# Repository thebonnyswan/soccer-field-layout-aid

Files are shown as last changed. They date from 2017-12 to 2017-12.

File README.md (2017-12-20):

# soccer-field-layout-aid
Soccer Field Layout Aid

Post hoc collection of code, documentation, and STL files for a soccer field layout aid. Design would be mounted on an existing chalk line marker, and monitors position to instruct user in field layout.

Project completed as part of coursework with Kai Kaneshina and Felipe Borja.

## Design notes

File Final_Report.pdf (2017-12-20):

# Technical Report

The Design Process and Testing of an Autonomous Soccer Field Layout System

To: | Claremont AYSO
From: | Elizabeth Poss Kai Kaneshima Felipe Borja
Date: | May 4, 2016

Abstract:

This report outlines the design process used to create an improved soccer field layout

system for Ms. Diane Flowers and her organization, AYSO Claremont. The team identified

objectives, constraints, and functions to reduce the time spent laying out the field, and improve

the accuracy and ease of use of the existing design. The resulting prototype used an Arduino

interface to autonomize the process. This design modified the existing painter, providing a low

cost alternative that users would be familiar with. While testing was limited by available

materials, all available metrics showed that the prototype would successfully be able to lay out

and paint soccer fields of different sizes accurately and in a substantially shorter amount of time

than before.

Table | of | Contents

List of Tables
List of Figures
I. Introduction
II. | Background and Research
III. | Methodology
a. Constraints
b. Objectives
IV. Conceptual Design
a. Functions
b. Means
c. Design Alternatives
d. Choice of Final Design
V. Designing and Prototyping
a. Hand Painter/Circle Apparatus
b. Wheel Encoder Apparatus/Sensor
c. User Interface
d. Coding
e. Physical Modifications on Painter
VI. | Testing and Results of Final Prototype
VII. | Recommendations
VIII. | Conclusion
IX. | Acknowledgements
X. References
XI. | Appendices
| 10.1 Revision of Initial Problem Statement
| 10.2 Project Management
| 10.3 Physical Modification and Installation Guide
| 10.4 Bill of Materials
| 10.5 Arduino Code

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
List | of | Figures
Figure 1. | Soccer Field Layout
Figure 2. | Alternative Layout Method
Figure 3. | Hand Painter
Figure 4. | Hand Painter Apparatus and Functions
Figure 5. | Arduino, Display and Sensor Apparatus
Figure 6. | Field Layout Order
Figure 7. | Painter and Physical Modifications
Figure 8. | Straight Line Guide (Retracted)
Figure 9. | Straight Line Guide (Extended)
Figure 10. | Electronics Box (Attached to Painter)
Figure 11. | Electronics Box (Diagram)
Figure 12. | Mounted Omega Bracket
Figure 13. | Omega Bracket (Diagram)
Figure 14. | Work Breakdown Structure
List | of | Tables
Table 1. | Piecewise Comparison Chart
Table 2. | Morph Chart
Table 3. | Best of Class Chart
Table 4. | Straight Line Angle Error
Table 5. | Right Angle Error Test Results
Table 6. | Success of Objectives
Table 7. | Success of Constraints
Table 8. | Bill of Materials

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
I. Introduction

Laying out and striping soccer fields is an often overlooked process that is vital for

effective game play. While straight lines and accurate angles are important for the players, they

are also important for the referees, who need to determine when the ball has gone out of play. If

a line is not straight or if the field is not dimensioned properly, the job of the referee is much

more difficult, and game play is negatively affected.

The current design to paint fields uses a four wheeled cart with metal brackets to hold a

can of paint upside down. When a trigger on the handle of the cart is squeezed, the nozzle of the

paint can is depressed, making it spray out paint below the cart. The current procedure has

several limitations. The wheels of the cart are attached very close to the cart’s chassis, which

prevents the cart from turning from side to side. While the locked wheels facilitate straight line

painting, it is difficult to paint the penalty arcs and center circle, thereby reducing accuracy.

Currently a tape measure is used to lay out the field, measuring from one side of the field to the

other. The corresponding end points of this line are then marked for later use. Ninety degree

angles for the corners of the field and other rectangles are simply ‘eyeballed’, limiting precision.

Furthermore, the amount of time required to layout a field takes approximately three hours and

painting over an existing field takes about ninety minutes. This process requires three to four

people. Fields need to be repainted every week, costing time and money for paint, because the

paint completely fades after two weeks, necessitating a complete relayout. As a result, the fields

can only be used for soccer, preventing the space from being utilized by other youth sports.

Thus, a product that allows for a faster layout and striping process, would reduce the time

demands, costs and allow fields to be repurposed for other activities.

Our liaison, Diane Flowers, presented the above design challenge to engineering students

at Harvey Mudd College, and requested that the students improve upon the existing painting

process. The students then visited the field and assisted the liaison in painting over an existing

field to gain a better understanding of the problems associated with the current process. The

initial problem statement follows below:

The lining of soccer fields is a challenging task that is often conducted by volunteers.

Frequently, the initial layout is challenging to achieve with respect to accurate angles

and distances. A solution is required that will make the positioning of the elements of a

soccer field easily identified on the field and will lead to immediate or almost immediate

marking of the field using conventional painting methods. The solution should identify the

points for all field painting. A very attractive solution would be one that is autonomously

capable of lining the field with limited human input.

II. | Background | Research

The team began by researching how other organizations paint soccer fields. Most

professional soccer fields have built in stakes to mark important points. However, professional

fields have one standard size, whereas the dimensions of youth soccer fields depend on the ages

of the players. In a meeting with our liaison, she emphasized the need for scalability. Thus, these

permanent modifications are not a logical choice for the design.

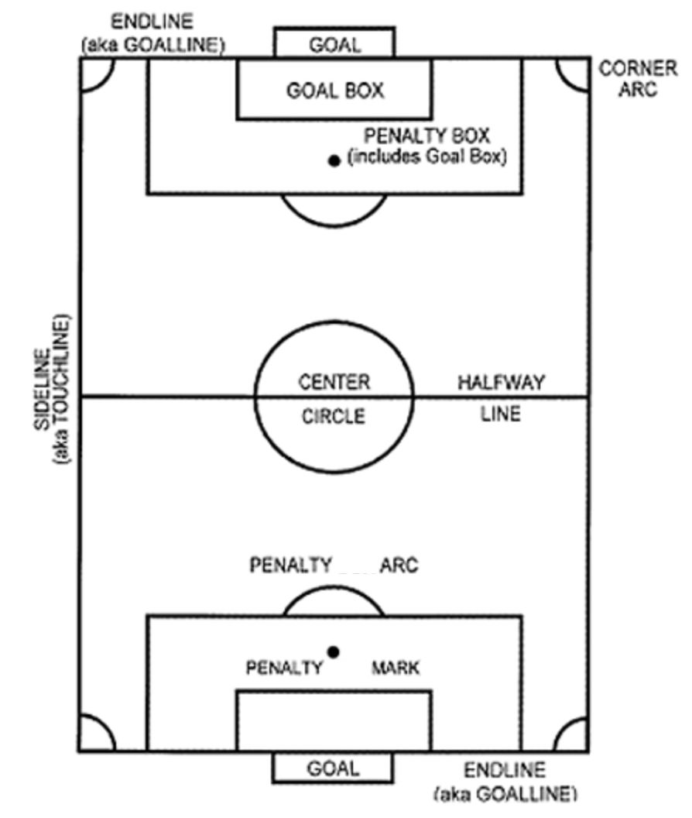
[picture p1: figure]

Figure 1. Soccer Field Layout

Soccer Field Kits has developed a design that uses a system of premarked tape measures

and a system of stakes to lay out a soccer field (cf. Figure 2). The tape measures would be

aligned at a 90 degree angle before using stakes to mark where the halfline, goal box, penalty

box, etc., should intersect with the existing line. While this process supposedly takes less than 20

minutes, it would require multiple people to hold the measuring devices and place down the stakes. Furthermore, there was no mention of how the lines would be painted or how straightness

could be guaranteed.

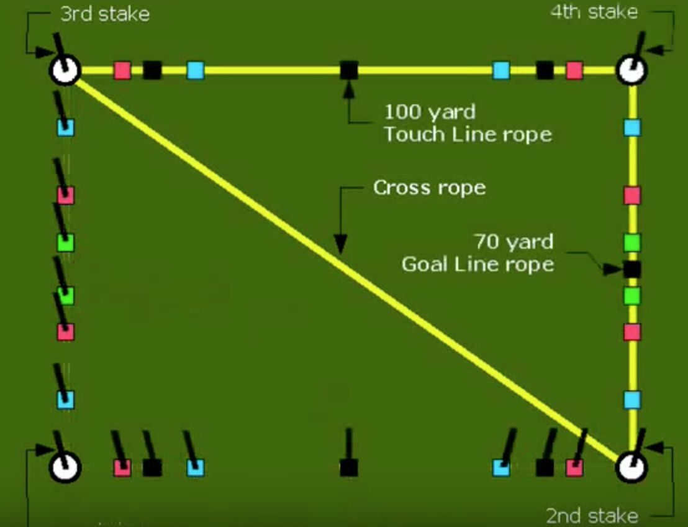
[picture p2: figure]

Figure 2. Alternative Layout Method

In addition, neither design is scalable, something that the liaison specifically requested.

Epic Sports Soccer sells a Ameri-Stripe Aerosol Marking Stick, referenced from here on

as a hand painter (cf. Figure 3). The design holds a can of paint, and uses the same trigger

method as the cart to spray out paint. The handpainter can be moved freely, which would be very

useful for painting curved lines. However, this means that this device could not be used to paint

straight lines.

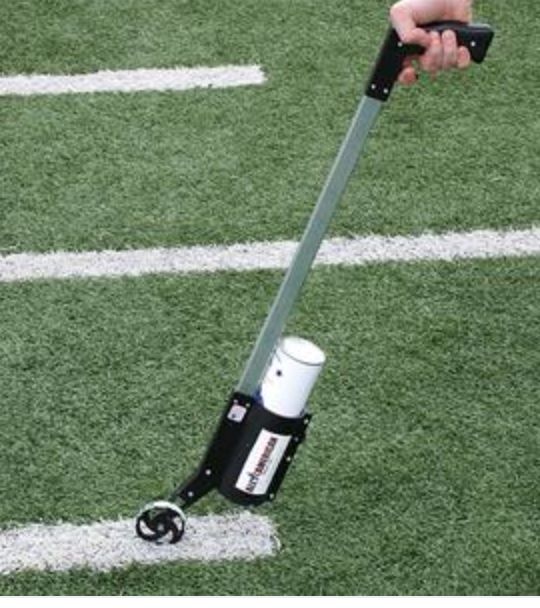
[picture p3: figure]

Figure 3. Hand Painter

III. | Methodology
A. | Constraints

Before deciding on possible objectives or necessary functions, the team decided to

identify the constraints governing the project, which came directly from the liaison following an

initial meeting. Constraints are limitations put on the design space that must be upheld regardless

of the situation. If a constraint is not met, the product has failed. Below are the constraints

associated with this project.

- The time to lay out the field must be under 3 hours: It currently takes 3 hours to

lay out a new field. This process simply takes too long and the product created

must reduce the amount of time needed.

- The time to stripe the field must take under 90 minutes: The liaison repaints the

field every week in order to make the lines more visible. As a result, the liaison

does not need to lay out the field again and simply needs to paint over the existing

lines. However, the error involved in the repainting process is quite high, as it is

hard to ensure that the paint is falling directly on top of the previous lines.

- No more than three to four operators: The layout process currently requires three

to four volunteers to manually lay out the field, as a tape measure is used to

measure out each dimension of the soccer field. Because multiple fields must be

painted, needing multiple people to paint a single field is inefficient. The design is

required to reduce the number of people necessary to layout a single field.

- Very low angle tolerance: There is no standard for creating the right angles for the

field. Currently, the user just ‘eyeballs’ it. The design must create very precise

angles in order to ensure the layout of an accurately measured field. Tests showed

that an error of about .5 degrees was acceptable.

- No prior user training necessary: The liaison specified that volunteers usually

paint the soccer field. Thus the product must be designed for users with no

previous knowledge. If a volunteer has no background painting a soccer field, the

product must be able to guide them.

- Only uses paint for drawing lines: The liaison specified that only paint can be

used for striping the fields, as chalk would kill the grass. Furthermore, the paint is

distributed by the same company that the liaison buys other materials from, so the

product must work with the existing type of paint can.

- The product must cost under $100.00: The current field striper costs

approximately $100.00. The design should cost less than this, or function with the

existing painter. Because the liaison works for a volunteer based company, the

product must be affordable.

- Line width must be between two to four inches: The lines painted by the field

must meet the standard width of two to four inches, which allows for the best

visibility by the soccer players and referees.

- No permanent modifications can be made to the borrowed field painter: The

liaison allowed the team to borrow the current field painter for testing. The team

was not allowed to make any permanent physical modifications to the cart.

B. Objectives

After determining the constraints, the team formulated the objectives for the product.

Objectives are goals that the product is desired to meet, but not necessary for functionality.

Below is a pairwise comparison chart, which compares objectives to each other and then awards

points to the more important objective. A total score for each objective was then calculated; the

objective with the highest score is the most important.

Table 1. Piecewise Comparison Chart

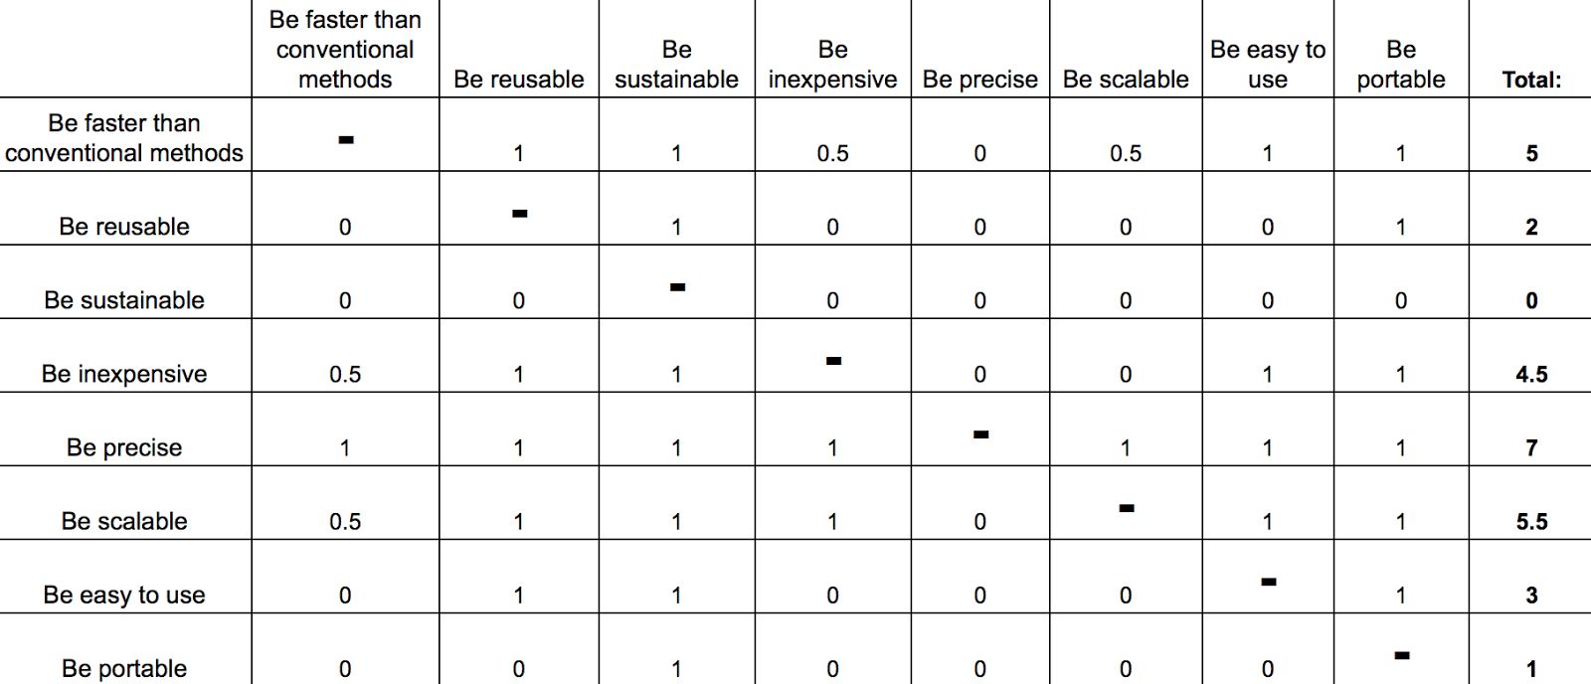
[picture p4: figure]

Below are the objectives ranked in order of importance.

1. Be precise: The liaison put tremendous emphasis on precision, as the field should

be a perfect rectangle that contains perfectly made circles, and goal and penalty

boxes that are placed at their precise locations.

2. Be scalable: The product should be able to lay out and paint soccer fields of

different dimensions. It should be able to accommodate standard field sizes, as

well as scale the field dimensions for areas of nonstandard size.

3. Be faster than conventional methods: The product should considerably decrease

the amount of time required to stripe and lay out a soccer field.

4. Be inexpensive: The product should not cost a lot to increase accessibility to

volunteer-based soccer leagues.

5. Be easy to use: The product should be fairly easy to use, as volunteers with no

prior experience often paint these fields.

6. Be reusable: The product should be able to be used many times without the need

for replacement, thus lowering the long term cost.

7. Be portable: The product should be fairly portable so that it can be used easily

used by only one person. In addition, it must be easily stored.

8. Be sustainable: The product should retain functionality for a reasonably long

period of time.

IV. | Conceptual | Design

Once the design space was fully defined, the team started searching for the best design

alternative. This process began by generating a large number of possible ways to fulfill the

desired objectives and then narrowing these options until the best one had been chosen.

A. Functions

A function is an action that the product performs. The functions are represented as verb

noun pairings.

- Scale field area
- Mark important field points
- Paint accurately over laid out lines
- Creates exact 90º angles
- Lay out straight lines
- Operate on multiple terrains (Because soccer games are played on grass and occasionally

dirt, the product should be able to operate on multiple terrains.)

B. Means

Next, the team explored possible means of fulfilling these functions. The team

brainstormed a large number of possible means with each corresponding to one of the functions

the product was meant to perform. These ideas were displayed in a Morph Chart, a structure

which allows us to group possible means by the functions they fulfill.

Table 2. Morph Chart

Scale field area | Computer program | Preset field types | User input | Physical scale | Phone application
Mark important field points | Tape measure | GPS marker | Paint | Stakes | Laser pointers
Allow users to accurately paint over laid out lines | Locked wheels | Metal marker, paint thing next to chassis | Hand painter attached to cord + stake for circles | Angled wheels on painting cart | Guiding piece of wood the width of the line
Creates exact 90º angles, | Angled guides | Intersection of two lines | Measuring angles | Tape measures | Laser guides
Lay out straight lines | Laser lever | Straight edge | Arduino
Operate on multiple terrains | Current wheel system | More visible paint | Rugged wheels
Produce Accurate Circles | Hand painter + string | String + stake system | Angled wheels
C. Design | Alternatives

Now, with a variety of means of fulfilling our design, the team attempted to evaluate

these means for compatibility with each other. This approach briefly set aside the efficiency or

success of the individual means, in favor of finding defined groups of means that would work

together effectively to fulfill our entire design. This allowed us to come up with a number of

design alternatives that could be evaluated for complete fulfillment of constraints, and then for

overall efficiency.

The design alternatives separated into two different design paths. The first was an

exercise in optimizing existing methods. The user would employ a system of stakes, tape

measures, and wood markers to lay out the field, then use the existing striping method to paint the field. The system of stakes and markers would be modified to allow for scalability, and

actions would be optimized to reduce time and number of users necessary. The second path was

a greater deviation from existing methods. The painting and layout process would be combined

into one, and the painter would be modified so that it could measure its position on the field. This

would be achieved by attaching a wheel encoder to the painter, allowing us to measure distance

traveled. An Arduino microcontroller would provide a user interface that would direct the user in

the steps of laying out the field. A third possibility briefly explored was the use of laser levels to

generate the straight lines of the field. This design would function much like the first path, but

using laser levels instead of string/tape measures to generate straight lines.

D. Choice | of | final | design

These design alternatives were first evaluated to ensure that they could fulfill all

constraints. During this evaluation the team chose to exclude the laser level based design,

realizing that we would not be able to buy the necessary equipment with the existing budget. The

team used a Best of Class Chart (cf. Table 3) to compare the effectiveness of the two remaining

designs. Each design's ability to fulfill the objectives was ranked (lower rank corresponds to

better fulfilment of objective), and ultimately the Arduino assisted painting method was found to

be more effective. Overall, the team supported this design because it represented a greater

improvement upon the field layout process, rather than just optimizing an existing process. This

design was also chosen because it combined the field layout and painting process. This marked a

significant improvement for the objective our client ranked most highly- layout time. Even if we

failed to decrease the layout time, combining the two processes would decrease the total time needed to lay out and paint a field. With the design chosen, the team began the process of

designing a functional prototype.

Table 3. Best of Class Chart

Design 1 | Design 2
Wheel encoder | Stakes + tape measure
arduino display | wood marker
led markers/display | paint over string/tape measure
Be faster than conventional methods | 1 | 2
Be reusable | 2 | 1
Be sustainable | 0.5 | 0.5
Be inexpensive | 1 | 2
Be precise | 1 | 2
Be scalable | 0.5 | 0.5
Be easy to use | 1 | 2
Be portable | 1 | 2

8 12

V. | Designing | and | Prototyping

A. Hand | Painter/Circle | Apparatus

The team began prototyping by creating the independent devices necessary for drawing

the circular segments of the soccer fields. The wheels of the painter are fixed and are thus

inadequate for drawing the curved segments of the field. The best course of action was to

produce a separate tool that facilitated the painting of the center circle, penalty arcs, and corner

arcs.

The hand painter was inspired by a compass (drawing tool) and by models seen during

background research. The full hand painter apparatus consisted of a purchased hand painter to

draw the circle, and a metal stake used to mark the center of the circle. The two were joined by a

length of string extending from a freely-rotating spool on the stake to a fitted metal connector on

the hand painter. The string was wound around the spool, with every yard marked by a black flap

of tape for ease of use. An alligator clip was used to hold the selected flap of tape onto the spool,

letting the user draw a circle of fixed radius. The spool and metal connector are at the same

height compared to the field, ensuring a radius of the exact length requested.

The hand painter is operated by a single person during the field painting process. During

the overall painting process, the user would be instructed to draw a circle or arc of a given radius

around a marked center point, using the hand painter connected to a stake using rope.

Specifically, the stake would be fixed in the ground at the center of the circle, and the

user would unravel a length of string equal to the desired radius. The string would then be

clamped in place and the operator would walk until the string was taut. Then, using the hand

painter, they could paint in a circle until the desired shape had been fully painted. The spool on the stake would rotated freely with the operator’s walk, to prevent tangling that could alter the

radius.

Once the circle was completed, the operator could roll the string back into the spool with

ease and continue painting the straight lines and angles of the soccer field until another circular

segment needed to be drawn. The combination hand painter and stake is sufficiently compact to

be carried in the paint cart’s storage basket without hindering its movement.

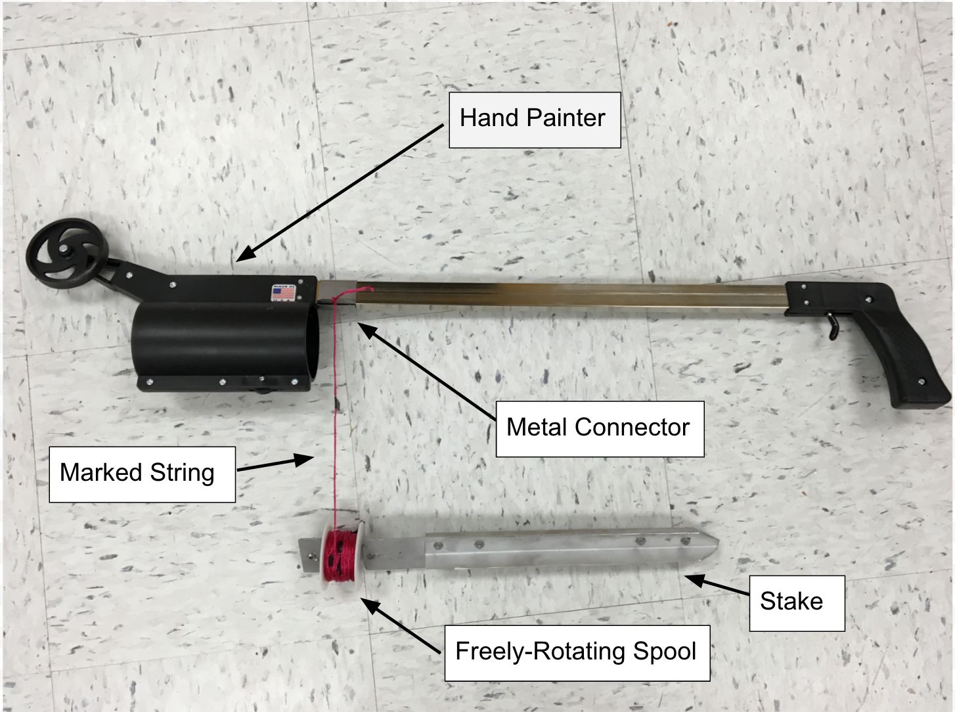
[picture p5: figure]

Figure 4. Hand Painter Apparatus and Functions

B. Wheel | Encoder | Apparatus/Sensor

The team choose to modify the painter with a wheel encoder. A wheel encoder is a sensor

attached to a wheel that measures the number of wheel rotations. Because the circumference of

the wheel is known, the distance that the painter has traveled can then be calculated. However, the addition of a wheel encoder can be achieved in many ways. Common methods include an

optical wheel encoder, in which a sensor measures light and dark patches on the wheel, or a limit

switch, in which a part of the wheel presses a switch every time it rotates past the sensor.

Given these options, the team had to choose a sensor that would act as a wheel encoder

and could attach to the painter without extensive modification. Because most optical wheel

encoders must be attached to the axle of the wheel, the team was forced to eliminate this option.

The fixed nature of the painter’s wheels meant that there was not enough space on the axle for an

optical wheel encoder. In addition, the possibility of dirt and grass collecting on the wheels of the

painter would introduce more sources of error. The team then considered using a limit switch - a

sensor most commonly designed as a piece of metal that senses when it has been depressed.

However, most limit switches have a limited range of motion, i.e., they cannot be moved both

forwards and backwards. This range of motion would be necessary for a painter, as it is moved

forward and backwards during normal use. This leaves the option of a rotary limit switch, a limit

switch with a much larger degree of possible movement. This sensor would reduce error by

making the units of rotation very clearly defined, with fewer sources of error. However, only a

few of the available rotary limit switches within our budget allowed for a full 180º of motion.

While a viable, inexpensive rotary limit switch was found, it would have required permanent

modifications to the painter to mount and test. Because permanent physical modifications were

not allowed for the prototype, the team choose to use a different approach for the prototype.

For the prototype, the team chose to engineer an optical wheel encoder using a

reflectance sensor. The reflectance sensor measures the reflectance of a surface, a value affected

by the color of a surface, and the distance between the sensor and the surface. The team mounted temporary black color markers on the existing spokes of the wheel for the reflectance sensor to

detect. This allowed the sensor to measure the number of rotations of the wheel. The team used

10 markers that were evenly spaced around the wheel at each of the existing spokes, to reduce

the error if the sensor failed to detect one of the markers.

The sensor used was a QRD1114 Digikey Reflectance Sensor. The circuit used was

sourced from the sensor array used in a previous engineering class (E11), because the sensor

array contained a backup photoreflectance sensor. Although the team did not use this sensor, it

allowed for the possibility of mounting a small LED somewhere on the wheel, and measuring

rotation by tracking the number of flashes of light measured.

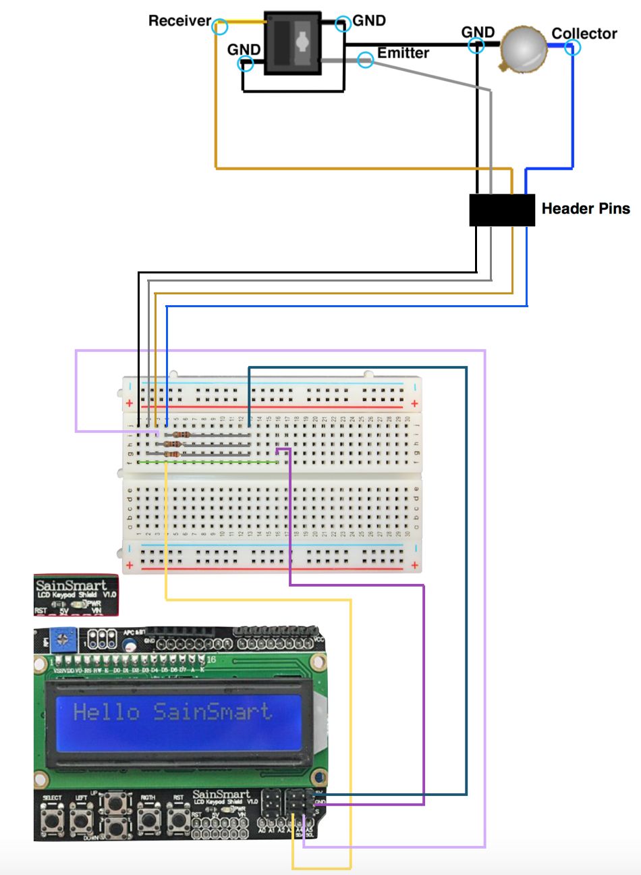
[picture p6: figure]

Figure 5. Arduino, Display and Sensor Apparatus

C. User Interface

Our design used an Arduino Uno microcontroller to calculate field dimensions and

formulate instructions for the user. These instructions were displayed using a SainSmart 1602

Liquid Crystal Display. This display had two rows that could display 16 characters, and

up/down/left/right, select, and restart buttons. This allowed the Arduino to display instructions to

the user, and for the user give inputs using the buttons. The sensor array was attached to the

Arduino, which was mounted to the LCD screen. This combination was powered using a

rechargeable battery pack, allowing the user to recharge the interface between uses. The interface

is controlled by the programmable Arduino, which was preloaded with our field layout program.

D. Coding

The layout of the field was directed by the Arduino, using a field layout program that the

team designed to minimize the time spent on the painting/layout process. First, the user is

prompted to choose from the standard field sizes: U8, U10, U12, U14, U16, and U19. Because

our client wanted a method to lay out non-standard sized fields, the program includes an “other

dimensions” option. This allows the user to input their own field dimensions. Because of the

limited input buttons, the user inputs only the length or width of the field by choosing each

individual digit by using up and down buttons to scroll through the numbers 0 to 9, and

confirming each digit with the select button.

The field size is the only real input the user needs to supply- the program immediately

begins instructing the user in their movements. This appears to the user as a series of

instructions- to move to the lower left corner of the field, to align the painter, and start painting.

All instructions followed the same format. For painter realignments that needed to be performed by the user, the program included a “press select to confirm” function that would pause the

program until the user has confirmed that they have completed the necessary steps. For straight

lines, the program knows the length of the line that needs to be painted, and displays to the user

how far they have traveled, and the final length of the line. This updates as the sensor reads the

rotations of the wheel, so the user can see in real time how much of the line they have painted. In

addition, when the user is painting straight lines, the user can press the left button to make the

program stop accepting inputs from the sensor. This means that the user can move the painter

without their movements being counted as part of the length of the line. This is necessary in

situations when the user needs to replace empty paint cans or if the user needs to realign the

painter.

With these generic instructions, the user moves around the field, first painting the

perimeter, then the left penalty and goal box, the centerline, and then finally the right field and

goal box. The penalty arcs are painted after the penalty and goal boxes, with the user instructed

to leave the stake as a marker and come back shortly after to paint the circle once the painter has

been moved away. The same process is used for the center circle, with the circle painted after the

centerline.

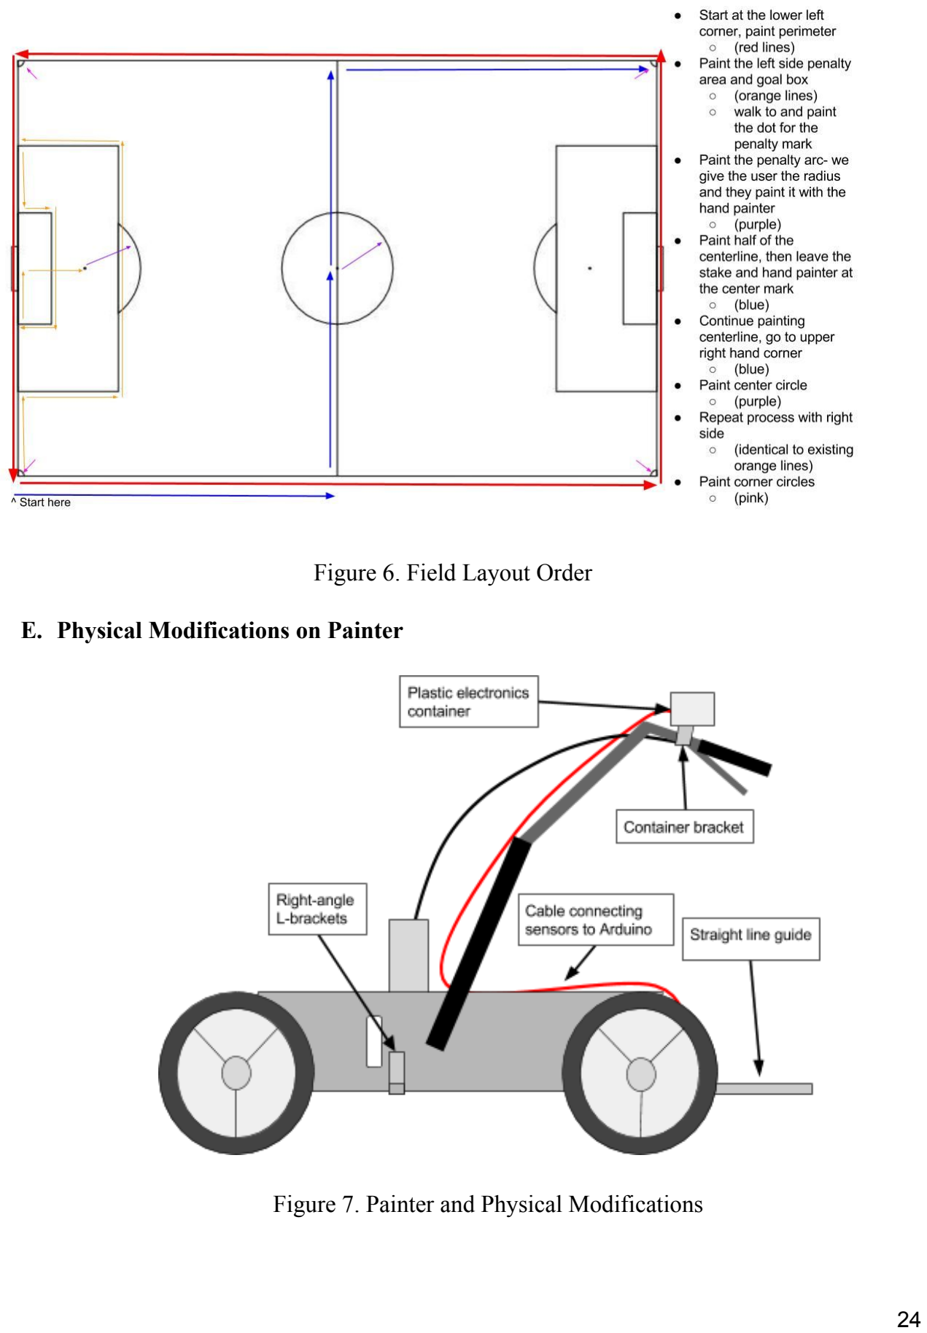
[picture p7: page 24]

Figure 6. Field Layout Order

E. Physical | Modifications | on | Painter

Figure 7. Painter and Physical Modifications

The first removable physical modification made to the painter was the attachment of a

pair of large L-brackets to the side of the painter, lined up with the point at which the paint is

sprayed. These brackets extend 8.25 inches in either direction, forming a straight line with the

paint spray point directly between them. These brackets were intended to facilitate the creation

of 90 degree angles. After the cart painted a line, the cart’s chassis would be aligned so that one

of the L-brackets (on the appropriate side) would cover part of the existing painted line. The next

line produced would then be perpendicular to the existing line, within an allowable tolerance of

.5 degrees.

In order to ensure that the lines produced by the painter were straight, a straight line

guide was added to the back of the cart. A long, straight piece of metal was extended from the

back of the cart so the operator could check its position against that of the line. This metal

extension was fashioned from a light piece of metal to prevent bending. It was positioned in such

a way that it would not restrict the operator’s movement. The straight line guide was 18.5 inches

in length when fully extended, but only 14.75 inches in length when rotated inwards. A bent

piece of metal was attached to the rotating joint of the line guide to ensure a constant angle of

180 degrees.

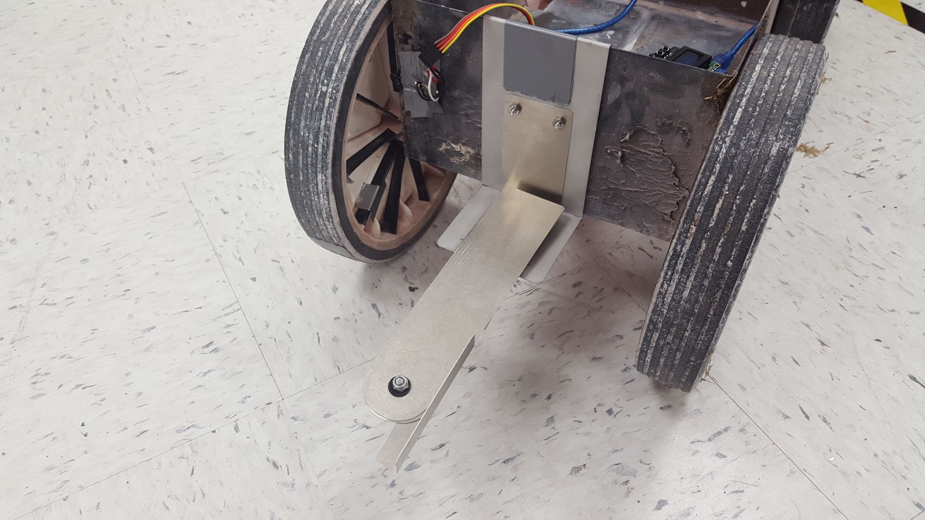
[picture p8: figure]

Figure 8. Straight Line Guide (Retracted)

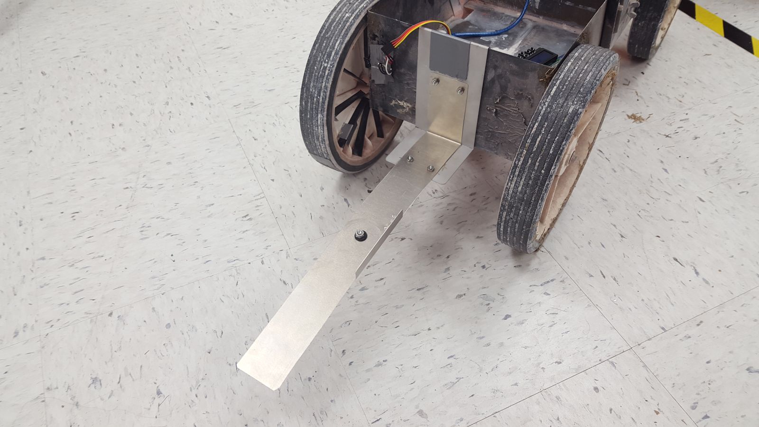
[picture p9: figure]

Figure 9. Straight Line Guide (Extended)

Next, the Arduino, display, and battery pack were mounted in an acrylic box attached to

the handle of the painter. This container also served to protect the electronics from

environmental exposures, but was equipped with access points for the Arduino serial port and the

battery charging cord. While original plan was to 3D print the container, the 3D printers were

experiencing technical difficulties. Instead the box was created by gluing together acrylic plates.

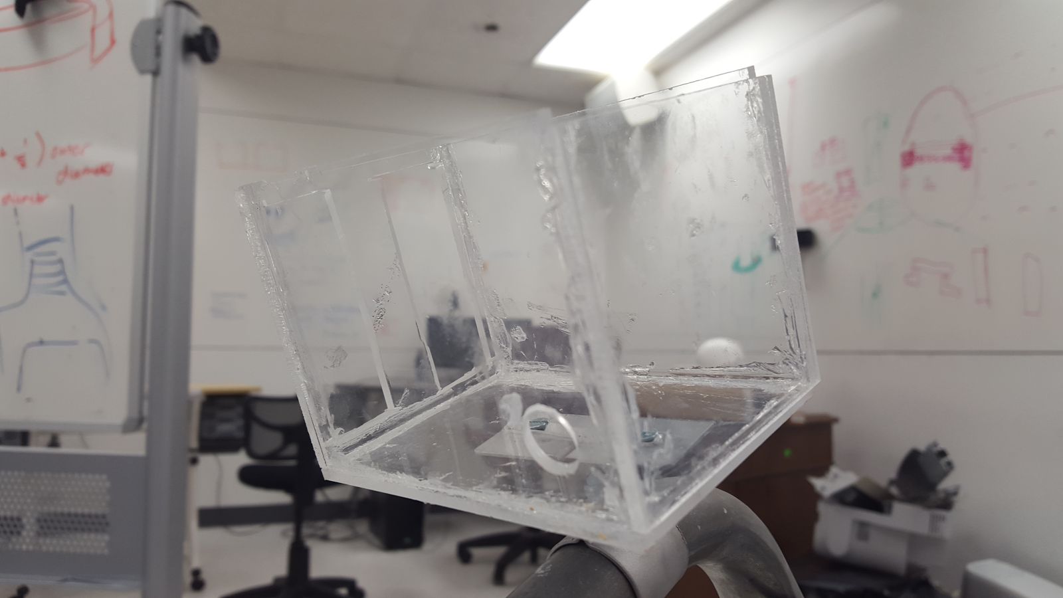
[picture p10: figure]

Figure 10. Electronics Box (Attached to Painter)

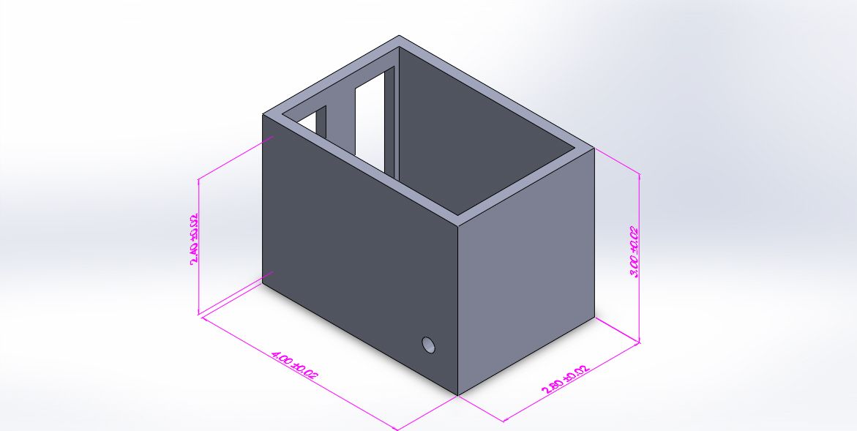
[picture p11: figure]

Figure 11. Electronics Box (Diagram)

A sheet metal omega-shaped mount was designed to hold the box in place on the handle.

The diameter of the mount needed to be precise, because the safety of the electrical components

in the box would depend on the tightness of the mount around the handle. Holes in the mount

would allow for the acrylic box to be mounted using screws.

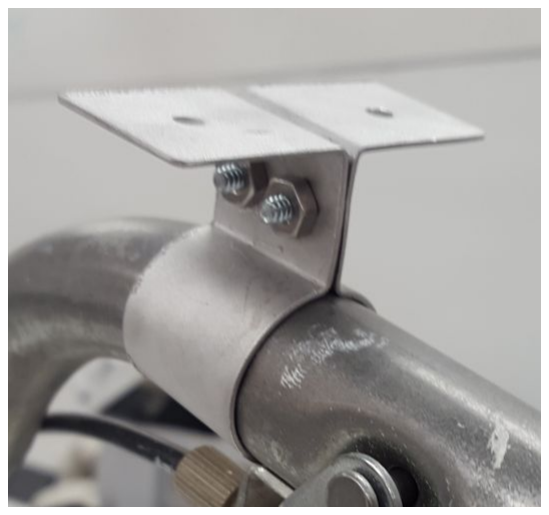
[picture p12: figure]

Figure 12. Mounted Omega Bracket

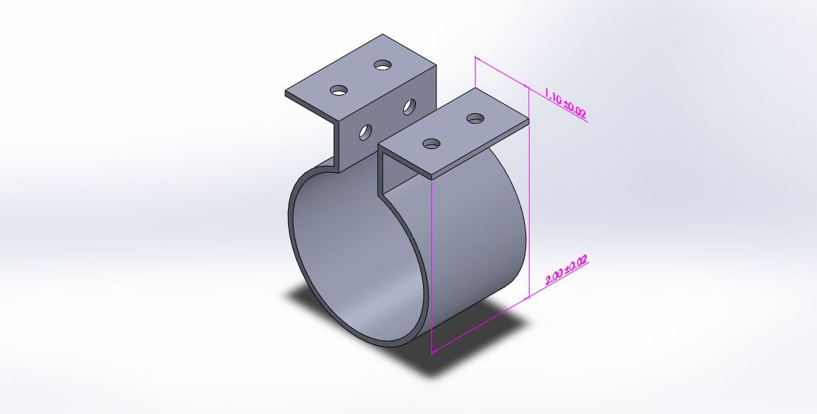
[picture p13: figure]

Figure 13. Omega Bracket (Diagram)

The final physical addition to the painter was the inclusion of a sensor mount that hangs

from the bottom of the chassis and protrudes from a hole in the chassis’ storage basket. It is

intended to hold the reflectance sensor close to the wheel so it could read the markers attached to

the spokes of the wheel. The sensor mount was painted black in order to prevent any interference

with the sensor, which detected the difference between light and dark colors. However, the

sensor mount was not used in our final prototype because it held the sensor too close to the

ground. This would be problematic if mud or dirt covered the sensor. Furthermore, this

positioning would make it much harder to access the sensor and clean it. The sensor was instead

attached to the back of the chassis, which was higher above the ground. Another advantage of this placement was that it granted protection from the paint spray, eliminating the need to create

a wind shield.

VI. | Testing | and | Results | of | Final | Prototype

The team ran a series of tests on the accuracy of the painting process. These tests were

limited by several factors, most significantly, the amount of spray paint available. Time and

budget constraints prevented the team from purchasing the quantity of paint necessary to paint an

entire field. Instead the team tested the layout order and measurements by following the

instructions from the display and drawing out the distances on a piece of paper. This created an

approximately scaled drawing of the full field, and allowed the team to confirm that the layout of

the field in the Arduino was accurate. Next, the team drew a series of short straight lines with the

painter to confirm that the wheels were locked enough to ensure straight lines. These tests

provided an estimated average angle displacement for straight lines, allowing the team to be

check that when the display directed the user to paint a straight line, the painted line would

actually be straight. These tests gave an average angle error of .0167 degrees (standard deviation

.006). This is virtually negligible. Observation during testing confirmed some waviness within

the line, but the endpoint of the line is accurate, so this will not matter in the overall construction

of the field. This, too, can be improved with practice on the part of the user.

The team then tested the error of the right angle method. This was first done by testing

the accuracy delivered from simply eyeballing a right angle from the side of the cart. Four trials

gave an average angle displacement of 0.4 degrees (standard deviation .216), a very small

margin that .would result in a maximum two feet displacement over a 100 yard line. While not

optimal, this level of error would result in an acceptable field. Unfortunately, further tests could not be conducted because of lack of additional paint. However, the team is confident that the

addition of the right angle guide would further reduce the error by a significant margin. From

this inference, the team concluded that the final angle error would be low enough to result in an

accurate field.

Table 4. Straight Line Angle Error

Error (in) | Total Length (in) | Angle Error
3.00 | 354 | 0.0085
4.87 | 213 | 0.0229
3.00 | 289 | 0.0158
2.00 | 102 | 0.0196
| Average | 0.0167
| Standard Deviation | 0.0062

Table 5. Right Angle Error Test Results

Right Angle Results
90.5
90.4
90.1
90.6
Average: 90.4
Standard Deviation:
0.21

Table 6. Success of Objectives

Objectives | Achievement
Be faster than conventional methods | From 3 or 4 hours to 1.5 hours with our model
Be reusable | ✔
Be sustainable | ✔
Be inexpensive | $94.30 (and painter)
Be precise | Yes (see testing)
Be scalable | “Other dimensions” feature
Be easy to use | Intuitive user interface
Be portable | Yes- attached to portable painter

Table 7. Success of Constraints

Constraints | Achievement
Under 3 hours for layout, (no more than 1.5 hours for striping) | ✔
No more than 3 or 4 operators | 1 operator
Low angle tolerance (very precise angles) | Yes (see testing)
No prior user training necessary | ✔
Only uses paint for drawing lines (no chalk) | ✔
Cost ~100 dollars, no more than the cost of a striper | ✔
Line width must be between 2 - 4 inches | ✔
No permanent modifications can be made to the currently field striper used | ✔

VII. Recommendations

While our prototype design is fairly accurate in its rotation counting, there is some error,

as a reflectance sensor simply detects a color reflected back to it. If the wheel of the cart were to

become very dirty, it is likely that the sensor would not be able to pick up any of the black lines

necessary for counting rotations. Furthermore, if any dirt or particulate matter covered the

sensor, it would not be able to accurately detect the number of rotations. As previously

mentioned, the team recommends replacing the reflectance sensor with a WLCA12-2 90 Degree

Rotary Roller Lever SPDT Momentary Limit Switch. This rotary limit switch would use the

existing spokes of the wheels to count the number of rotations. This sensor would have a much

better defined method of measurement, giving it a much lower possibility for error.

There are some improvements that can be made to the coding portion of the design as

well. Ideally, the team would have included a function that could subtract distance traveled, if the

volunteer accidentally moved the cart backwards. However, this improvement could not have

been made with the reflectance sensor. The addition of the rotary limit switch would allow the

sensor to detect forward and backward motion, letting the user change the measured distance

accordingly. We also could have further optimized the user interface. Additions like a numeric

keypad for inputting field dimensions, or scrolling text instructions would make the user

interface more friendly, but due to time constraints, the team chose not to pursue them during

prototyping in favor of producing a fully functional design.

VIII. | Conclusion
| Overall, the tested prototype performed the necessary functions, met all the constraints,

and achieved all the objectives. The design was chosen from several different alternatives based

on the best of class and pairwise comparison charts. The final prototype costs approximately

$94.30 to produce, with the hand painter using most of the budget due to high shipping cost.

While the team could have tried to make a hand painter on their own, time constraints made

buying a the pre-existing design the most feasible option. During the design process, the team

decided to add on several physical modifications to the cart in order to allow for line straightness

and right angle precision. These were achieved by attaching an extended piece of metal to the

back of the cart and L-shaped brackets to the sides of the cart. The prototype will significantly

reduce the amount of time needed to lay out and paint a field, and needs only one operator.

While we cannot predict the exact time it would take to lay out and paint a field, we predict it

would be similar to the time it previously took to only paint the field, roughly ninety minutes.

Furthermore, our method is more autonomized, and can paint all types of standard field size, as

well as fields of intermediate size. The addition of an Arduino takes any duty of calculation away

from the user, with their only necessity to input the length and width of the desired field. This

method also produces a field of necessary accuracy for practical use. While extensive testing was

not possible, the team is confident that the added modifications will greatly reduce error and

successfully produce a useable field.

IX. | Acknowledgements
| The team would like to thank Professor Srebotnjak for her invaluable advice as our

advisor. Alex Alves played a major role in helping the team set up their Arduino and sensors,

and Evan Kahn provided advice for machining and coding. We extend our thanks to Patrick

McKeen for his recommendations and ideas throughout the design process. We also

acknowledge the Harvey Mudd College Department of Engineering for funding our project.

Finally, we would like to thank our liaison, Ms. Diane Flowers, for letting the team use her

painter, and for doing everything she could to facilitate our work.

X. References

"Ameri-Stripe Aerosol Marking Stick." Soccer.EpicSports. Epic Sports, n.d. Web. 1 May 2016

"Arduino LCD KeyPad Shield (SKU: DFR0009)." DFRobot Wiki. DFRobot Wiki, n.d. Web. 10 Mar. 2016.

BrightCore. "How to Layout a Soccer Field Quickly." YouTube. YouTube, 07 Sept. 2010. Web. 10 May 2016.
Clark, Christopher. "Autonomous Passenger Vehicles." (n.d.): n. pag. E11 Mudduino Reference. Harvey Mudd College. Web. 1 May 2016
"Lucidchart." Lucidchart. N.p., n.d. Web. 01 May 2016.

MarkersInc. "Field Marking Equipment - Simple, Easy, Fast Field Lining System." YouTube. YouTube, 03 Oct. 2011. Web. 10 Mar. 2016.

"SainSmart LCD Keypad Shield For Arduino Duemilanove UNO MEGA2560 MEGA1280." SainSmart 1602 LCD Keypad Shield for Arduino Duemilanove UNO MEGA2560 MEGA1280 3D Printing, Arduino, Robotics. N.p., n.d. Web. 01 May 2016.

"Soccer Field Dimensions and Layout Tool for All Ages." Trumark Athletics Field Markers. Trumark Athletics, n.d. Web. 10 Mar. 2016.

"Soccer Field Marking Paint | Striping Lining Painting Soccer Lines." US Specialty Coatings. US
Specialty Coatings, 2007. Web. 15 Mar. 2016.

Truscomfg. "New Way To Do Hash Marks And Border Your Football Field, Trueline Stripers New Models." YouTube. YouTube, 08 July 2010. Web. 10 Mar. 2016.

"WLCA12-2 90 Degree Rotary Roller Lever SPDT Momentary Limit Switch." : Amazon.co.uk: DIY & Tools. N.p., n.d. Web. 01 May 2016.

"2013 Version Arduino UNO R3 ATmega328P Development Module 2013 Version with Free USB Cable." Http://www.gearbest.com. N.p., n.d. Web. 01 May 2016.

XI. | Appendices
10.1 | Revision | of | the | initial | problem | statement

The team decided to revise the liaisons initial problem statement in order to remove any

sort of error, bias, implied solutions and to clarify any ambiguity. Below is the revised problem

statement.

Design a simple product that allows for the rapid and precise layout of different
sized soccer fields using limited human input and traditional painting methods.

10.2 | Project | Management

The team used a work breakdown structure to organize the design process, which is

shown below.

Figure 14. Work Breakdown Structure

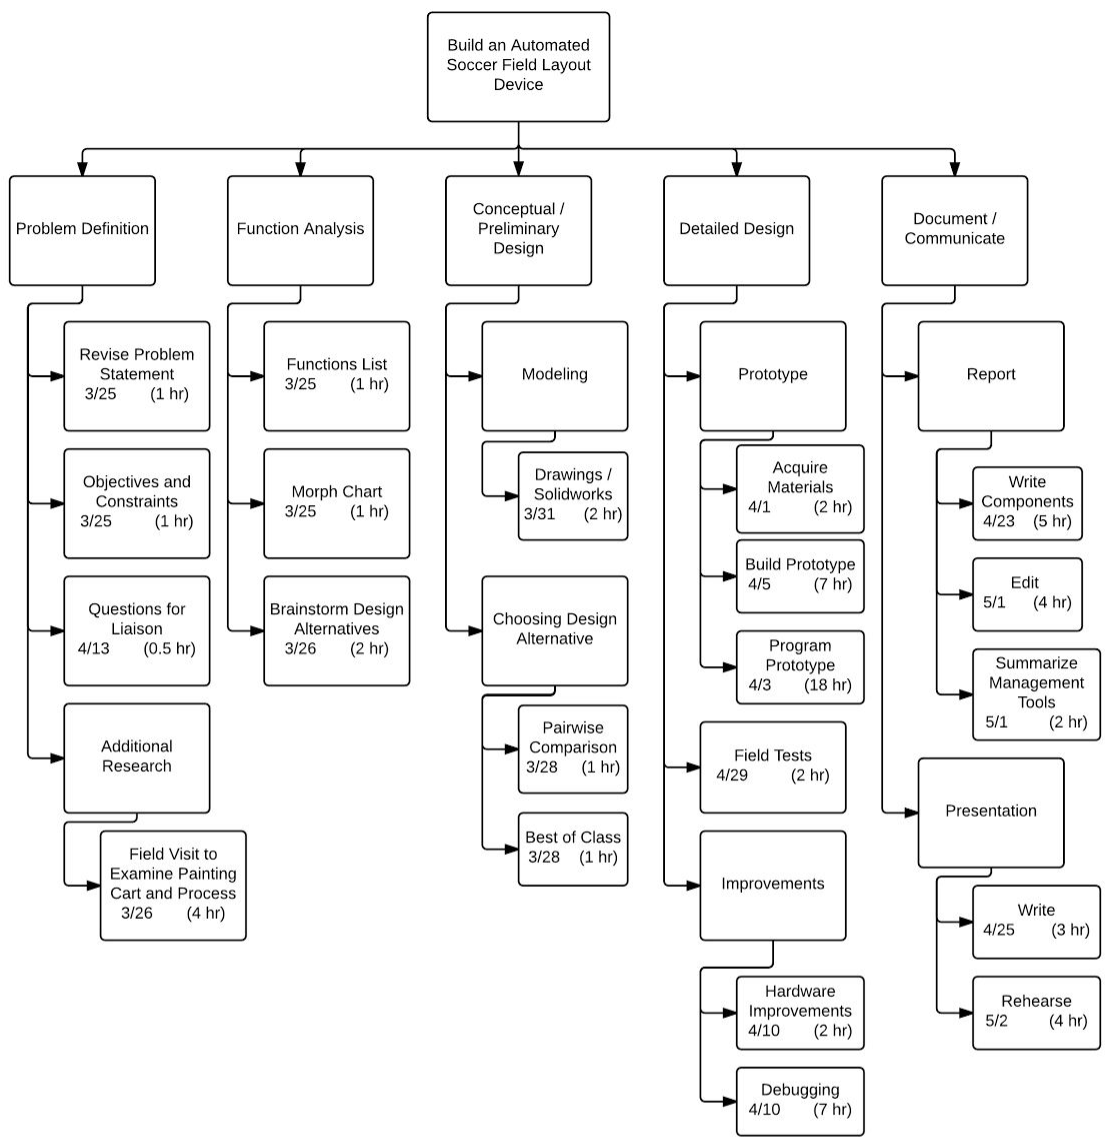
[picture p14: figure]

10.3 | Physical | Modification | and | Installation | Guide

The physical modifications are comprised of the following 5 pieces:
- Clear plastic electronics holder box
- Metal electronics omega-shaped bracket, composed of a circular segment with two perpendicular offshoots
- Folding rear line-guide
- Right-angle guides (2)

In order to attach the physical modifications to the cart, the following fasteners are required:
- 6-32 x ½ bolts (8)
- 6-32 nuts (8)

For attaching the right-angle guides and the rear line-guide, a hand drill with a 5/32’’ bit will be required.

Attaching the Electronics Box to the Handle
1. Attach the omega-shaped bracket onto the handle of the cart with the offshoots facing upwards.
2. Squeeze the neck of the bracket together.
3. Run two 6-32 x ½ bolts through the aligned holes in the neck and thread two 6-32 nuts on the other side. Tighten the nuts firmly.
4. Align the slot at the bottom of the electronics box with the holes in the top of the offshoot.
5. Run two 6-32 x ½ bolts through the slot in the electronics box and the holes in the offshoots of the bracket. Thread two 6-32 nuts onto the other end of the bolts and tighten them firmly.
6. You can now place the electronics inside the attached box.

Attaching the Folding Rear Line-Guide to the Back of the Cart
1. Rest the U-shaped part of the rear line guide on the back panel of the cart so that each edge of the rear line-guide is approximately 2.75’’ from its respective side of the cart.
2. There are 2 holes on the bottom of the rear-line guide. Line the drill up with those holes and extend them through the back of the cart.
3. Run two 6-32 x ½ bolts through the holes in the cart you created and their corresponding holes in the rear-line guide. Thread two 6-32 nuts onto the other ends of the bolts and tighten them firmly.

Attaching the Right-Angle Guides to the Side of the Cart

1. On the left side of the cart, drill a ⅛’’ hole 2.75’’ from the front wheel and ½’’ from the bottom of the cart so that the long segment of the right-angle guide is nearly flush with the bottom of the cart.
2. Insert a 6-32 x ½ bolt through the hole in the cart and the corresponding hole on the right-angle guide, then thread a 6-32 nut on the protruding bolt.
3. Tighten the nut, ensuring that the long edge of the right-angle guide is the one closest to the bottom of the cart.
4. Repeat steps 1-3 on the right side of the cart.

10.4 | Bill | of | Materials

Table 8. Bill of Materials

Material | Supplier | Quantity | Cost (USD)
LCD Keypad | SainSmart | 1 | $13.99
Arduino microcontroller | Arduino | 1 | $9.99
Hand painter | Epic Sports | 1 | $25.39
NiMH 7.2 V Battery | BatterySpace | 1 | $15.95
Tamiya Battery Charger | BatterySpace | 1 | $18.95
2.1 mm power cable | Digikey | 1 | $3.33
400-point breadboard | Pololu | 1 | $3.38
QRD1114 Reflectance Sensor | Digikey | 1 | $1.31
BPW77NA Phototransistor | Digikey | 1 | $1.91
Resistors | Digikey | 3 | $0.10
Total Cost | - | - | $94.30
10.5 | Arduino | Code

See attached email for the full code.

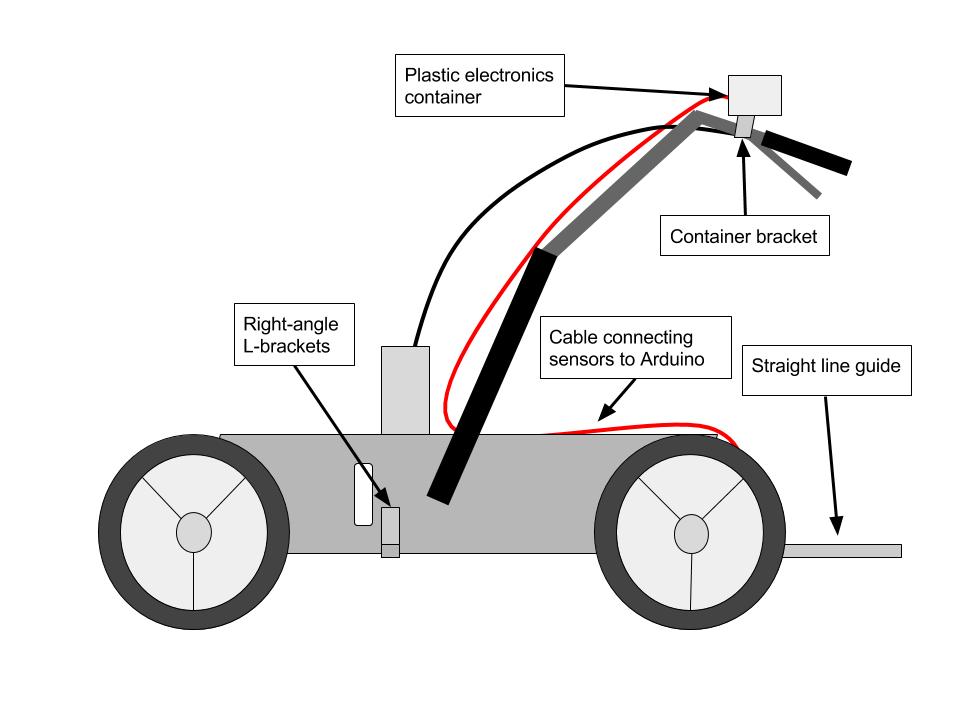
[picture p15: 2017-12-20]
Modified Cart Drawing.jpg

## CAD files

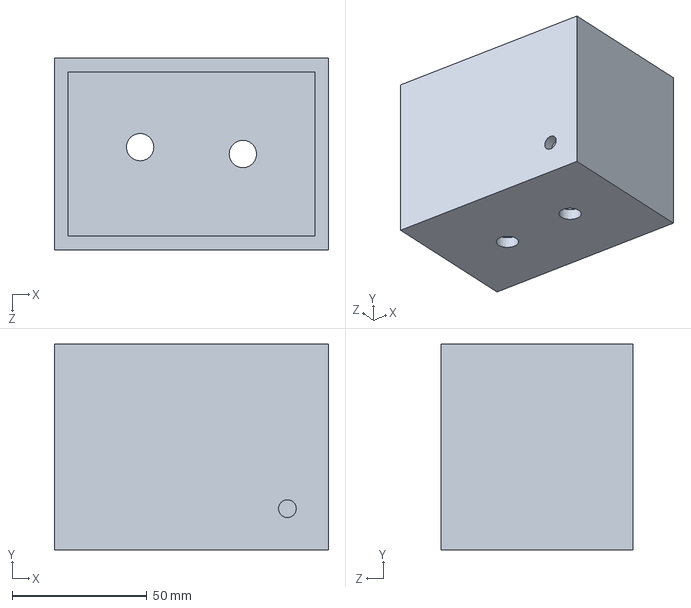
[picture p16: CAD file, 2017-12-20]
Electronics Box.SLDPRT
101.6 x 76.2 x 71.1 mm

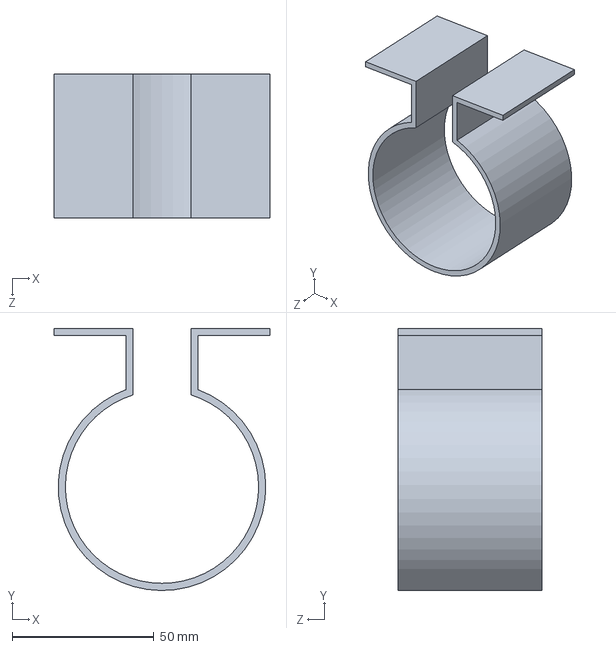
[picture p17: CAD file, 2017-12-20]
Handle Attachment.SLDPRT
76.2 x 92.5 x 50.8 mm

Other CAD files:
Electronics Box.STL

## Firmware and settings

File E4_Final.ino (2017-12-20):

// E4 Soccer Field Project

// REFLECTANCE SENSOR CONSTANTS
# define whitethreshold 500

// SENSOR PIN DEFINITIONS
#define REFLECTSENSOR 18
#define PHOTO 19

#define WHEELDIAMETER 10
#define ROTATIONCONSTANT .0873
// use instead of convert to length, value added for every marker tic

#include <LiquidCrystal.h>
LiquidCrystal lcd(8, 13, 9, 4, 5, 6, 7);

// __________________________________________BUTTON DEFINITIONS
// define some values used by the panel and buttons
int lcd_key     = 0;
int adc_key_in  = 0;
#define btnRIGHT  0
#define btnUP     1
#define btnDOWN   2
#define btnLEFT   3
#define btnSELECT 4
#define btnNONE   5

// _____________________________________________________________________ SETUP
void setup() {
  // put your setup code here, to run once:
  Serial.begin(9600);
  initSensors();
  lcd.begin(16, 2);
  lcd.setCursor(0, 0);


  straightlinefunction(100);
  //startpainting();
  //runotherfield();
}





// SENSOR TESTING
void initSensors()
{
  pinMode(REFLECTSENSOR, INPUT);
  pinMode(PHOTO, INPUT);
  int refl = analogRead(REFLECTSENSOR - 14);
  int photo = analogRead(PHOTO - 14);
}

void testSensors()
{
  int refl = analogRead(REFLECTSENSOR - 14);
  int photo = analogRead(PHOTO - 14);

  Serial.print("Refl sensor: ");
  Serial.println(refl);
  //Serial.print("Phototransistor: ");
  //Serial.println(photo);

  Serial.println(" ");
  delay(500);
}

void loop() {
  // put your main code here, to run repeatedly:

  //testSensors();

}

// _______________________________________________________FIELD SIZE CALCULATION
void calculatefield(float length, float width)
{
  // all measurements in yards
  float circlediameter = length / 10;
  float penaltyarc = length / 10;
  float penaltymark = penaltyarc + 2;
  float penatlywidth;
  float halfline = length / 2;
  float goalarea = length + width - 30;
  float goallength = 6;
  float goalwidth = goalarea - goallength;
  float penaltyarea = 2 * goallength + 2;
  float penaltylength = width / 2 + 2 - .5 * sqrt(width * width + 8 * width + 16 - 4 * penaltyarea);
}

// __________________________________________________BUTTON READING
// read the buttons
int read_LCD_buttons()
{
  adc_key_in = analogRead(0);      // read the value from the sensor
  // my buttons when read are centered at these valies: 0, 144, 329, 504, 741
  // we add approx 50 to those values and check to see if we are close
  if (adc_key_in > 1000) return btnNONE; // We make this the 1st option for speed reasons since it will be the most likely result
  // For V1.1 us this threshold
  if (adc_key_in < 50)   return btnRIGHT;
  if (adc_key_in < 250)  return btnUP;
  if (adc_key_in < 450)  return btnDOWN;
  if (adc_key_in < 650)  return btnLEFT;
  if (adc_key_in < 850)  return btnSELECT;

  // For V1.0 comment the other threshold and use the one below:
  /*
    if (adc_key_in < 50)   return btnRIGHT;
    if (adc_key_in < 195)  return btnUP;
    if (adc_key_in < 380)  return btnDOWN;
    if (adc_key_in < 555)  return btnLEFT;
    if (adc_key_in < 790)  return btnSELECT;
  */


  return btnNONE;  // when all others fail, return this...
}

// ________________________________________________________Initial User Interface
void startpainting()
{
  boolean endfunction = false;
  lcd.setCursor(0, 0);
  lcd.print("Choose field by");
  lcd.setCursor(0, 1);
  lcd.print("holding select.");
  delay(2000);
  lcd.clear();

  lcd.setCursor(0, 0);
  lcd.print("U8 Field");
  int timecounter = millis();
  while (millis() < timecounter + 2000);
  {
    delay(50);
    if (read_LCD_buttons() == 4)
    {
      runU8field();
      endfunction = true;
    }
  }
  if (endfunction == true)
  {
    return;
  }
  delay(1000);

  lcd.setCursor(0, 0);
  lcd.print("U10 Field");
  timecounter = millis();
  while (millis() < timecounter + 2000);
  {
    delay(50);
    if (read_LCD_buttons() == 4)
    {
      runU10field();
      endfunction = true;
    }
  }
  if (endfunction == true)
  {
    return;
  }
  delay(1000);

  lcd.setCursor(0, 0);
  lcd.print("U12 Field");
  timecounter = millis();
  while (millis() < timecounter + 2000);
  {
    delay(50);
    if (read_LCD_buttons() == 4)
    {
      runU12field();
      endfunction = true;
    }
  }
  if (endfunction == true)
  {
    return;
  }
  delay(1000);

  lcd.setCursor(0, 0);
  lcd.print("U14 Field");
  timecounter = millis();
  while (millis() < timecounter + 2000);
  {
    delay(50);
    if (read_LCD_buttons() == 4)
    {
      runU14field();
      endfunction = true;
    }
  }
  if (endfunction == true)
  {
    return;
  }
  delay(1000);

  lcd.setCursor(0, 0);
  lcd.print("U16 Field");
  timecounter = millis();
  while (millis() < timecounter + 2000);
  {
    delay(50);
    if (read_LCD_buttons() == 4)
    {
      runU16field();
      endfunction = true;
    }
  }
  if (endfunction == true)
  {
    return;
  }
  delay(1000);

  lcd.setCursor(0, 0);
  lcd.print("U19 Field");
  timecounter = millis();
  while (millis() < timecounter + 2000);
  {
    delay(50);
    if (read_LCD_buttons() == 4)
    {
      runU19field();
      endfunction = true;
    }
  }
  if (endfunction == true)
  {
    return;
  }
  delay(1000);

  lcd.setCursor(0, 0);
  lcd.print("other dimensions");
  timecounter = millis();
  while (millis() < timecounter + 2000);
  {
    delay(50);
    if (read_LCD_buttons() == 4)
    {
      runotherfield();
      endfunction = true;
    }
  }
  if (endfunction == true)
  {
    return;
  }
  delay(1000);
}


// ____________________________________________PRESET FIELD FUNCTIONS
void runU8field()
{
  lcd.clear();
  lcd.setCursor(0, 0);
  lcd.print("chosen U8");
  delay(1000);
  float U8length = 50;
  float U8width = 25;
  U8fielddirections(U8length, U8width);
  return;
}

void runU10field()
{
  lcd.clear();
  lcd.setCursor(0, 0);
  lcd.print("chosen U10");
  delay(1000);
  float U10length = 80;
  float U10width = 40;
  runfullfielddirections(U10length, U10width);
  return;

}

void runU12field()
{
  lcd.clear();
  lcd.setCursor(0, 0);
  lcd.print("chosen U12");
  delay(1000);
  float U12length = 100;
  float U12width = 50;
  runfullfielddirections(U12length, U12width);
  return;

}

void runU14field()
{
  lcd.clear();
  lcd.setCursor(0, 0);
  lcd.print("chosen U14");
  delay(1000);
  float U14length = 100; // INPUT THIS AFTER CLIENT INFO
  float U14width = 50; // INPUT THIS AFTER CLIENT INFO
  runfullfielddirections(U14length, U14width);
  return;
}

void runU16field()
{
  lcd.clear();
  lcd.setCursor(0, 0);
  lcd.print("chosen U16");
  delay(1000);
  float U16length = 100; // INPUT THIS AFTER CLIENT INFO
  float U16width = 50; // INPUT THIS AFTER CLIENT INFO
  runfullfielddirections(U16length, U16width);
  return;
}

void runU19field()
{
  lcd.clear();
  lcd.setCursor(0, 0);
  lcd.print("chosen U19");
  delay(1000);
  float U19length = 100; // INPUT THIS AFTER CLIENT INFO
  float U19width = 50; // INPUT THIS AFTER CLIENT INFO
  runfullfielddirections(U19length, U19width);
  return;
}

void runotherfield()
{
  lcd.clear();
  lcd.setCursor(0, 0);
  lcd.print("chosen other");
  delay(2000);

  lcd.clear();
  lcd.setCursor(0, 0);
  lcd.print("input field");
  lcd.setCursor(0, 1);
  lcd.print("length");
  delay(1000);

  int digitone = 0;
  int digittwo = 0;
  int digitthree = 0;

  // code for first digit

  lcd.clear();
  lcd.setCursor(0, 0);
  lcd.print("choose digit 1");
  lcd.setCursor(7, 1);
  lcd.print(digitone);
  lcd.setCursor(8, 1);
  lcd.print(digittwo);
  lcd.setCursor(9, 1);
  lcd.print(digitthree);

  digitone = digitinput(1);
  delay(1000);

  lcd.clear();
  lcd.setCursor(0, 0);
  lcd.print("choose digit 2");
  lcd.setCursor(7, 1);
  lcd.print(digitone);
  lcd.setCursor(8, 1);
  lcd.print(digittwo);
  lcd.setCursor(9, 1);
  lcd.print(digitthree);

  digittwo = digitinput(2);
  delay(1000);

  lcd.clear();
  lcd.setCursor(0, 0);
  lcd.print("choose digit 3");
  lcd.setCursor(7, 1);
  lcd.print(digitone);
  lcd.setCursor(8, 1);
  lcd.print(digittwo);
  lcd.setCursor(9, 1);
  lcd.print(digitthree);

  digitthree = digitinput(3);
  delay(1000);

  int fieldlength = 100 * digitone + 10 * digittwo + digitthree;

  digitone = 0;
  digittwo = 0;
  digitthree = 0;

  lcd.clear();
  lcd.setCursor(0, 0);
  lcd.print("input field");
  lcd.setCursor(0, 1);
  lcd.print("length");
  delay(1000);

  // code for first digit

  lcd.clear();
  lcd.setCursor(0, 0);
  lcd.print("choose digit 1");
  lcd.setCursor(7, 1);
  lcd.print(digitone);
  lcd.setCursor(8, 1);
  lcd.print(digittwo);
  lcd.setCursor(9, 1);
  lcd.print(digitthree);

  digitone = digitinput(1);
  delay(1000);

  lcd.clear();
  lcd.setCursor(0, 0);
  lcd.print("choose digit 2");
  lcd.setCursor(7, 1);
  lcd.print(digitone);
  lcd.setCursor(8, 1);
  lcd.print(digittwo);
  lcd.setCursor(9, 1);
  lcd.print(digitthree);

  digittwo = digitinput(2);
  delay(1000);

  lcd.clear();
  lcd.setCursor(0, 0);
  lcd.print("choose digit 3");
  lcd.setCursor(7, 1);
  lcd.print(digitone);
  lcd.setCursor(8, 1);
  lcd.print(digittwo);
  lcd.setCursor(9, 1);
  lcd.print(digitthree);

  digitthree = digitinput(3);
  delay(1000);

  int fieldwidth = 100 * digitone + 10 * digittwo + digitthree;

  runfullfielddirections(fieldlength, fieldwidth);
}

int digitinput(int digitnumber)
{
  int digit = 0;
  int curse = digitnumber+6;

  boolean selectpressed = false;

  while (selectpressed == false)
  {
    if (read_LCD_buttons() == 4)
    {
      selectpressed = true;
    }
    if (read_LCD_buttons() == 1)
    {
      if (digit == 9)
      {
        digit = 9;
      }
      else
      {
        digit += 1;
        lcd.setCursor(curse, 1);
        lcd.print(digit);
      }
      delay(175);
    }
    if (read_LCD_buttons() == 2)
    {
      if (digit == 0)
      {
        digit = 0;
      }
      else
      {
        digit -= 1;
        lcd.setCursor(curse, 1);
        lcd.print(digit);
      }
      delay(175);
    }


  }

  selectpressed = false;

  return digit;
}

// ________________________________________ FULL NONSPECIFIC FIELD INSTRUCTIONS
void runfullfielddirections(int length, int width)
{
  // all measurements in yards
  float circleradius = length / 10;
  float penaltyarc = length / 10;
  float penaltymark = penaltyarc + 2;
  float penaltywidth = penaltymark * 3;
  float halfline = length / 2;
  float goalarea = length + width - 30;
  float goallength = 6;
  float goalwidth = goalarea - goallength;
  float penaltyarea = 2 * goallength + 2;
  float penaltylength = width + 4 - penaltywidth;

  // Instruct the user to paint the outside rectangle.
  lcd.clear();
  lcd.setCursor(0, 0);
  lcd.print("Paint field");
  lcd.setCursor(0, 1);
  lcd.print("perimeter:");
  delay(3000);
  lcd.clear();

  // Go to bottom left corner.
  lcd.setCursor(0, 0);
  lcd.print("Go to bottom");
  lcd.setCursor(0, 1);
  lcd.print("left corner.");
  delay(2000);
  lcd.clear();
  pressselecttoconfirm();
  
  // mark the bottom line of the perimeter
  lcd.clear();
  lcd.print("Face along the ");
  lcd.setCursor(0, 1);
  lcd.print("lower field edge");
  lcd.setCursor(0, 0);
  delay(1000);
  straightlinefunction(length);
  delay(1000);


  // mark the right side of the perimeter
  leftturn();
  pressselecttoconfirm();
  delay(1000);
  straightlinefunction(width);

  // mark the top of the perimeter
  leftturn();
  delay(1000);
  pressselecttoconfirm();
  straightlinefunction(length);

  // mark the left side of the perimeter
  leftturn();
  delay(1000);
  pressselecttoconfirm();
  straightlinefunction(width);

  // paint penalty box
  // turn around to paint penalty area
  lcd.clear();
  lcd.setCursor(0, 0);
  lcd.print("Turn around.");
  pressselecttoconfirm();
  float topenalty = (width - goalwidth)/2;
  straightlinenopainting(topenalty);

  // paint right side of penalty box
  rightturn();
  delay(1000);
  pressselecttoconfirm();
  straightlinefunction(penaltylength);

  // mark the outside of the penalty box
  leftturn();
  delay(1000);
  pressselecttoconfirm();
  straightlinefunction(penaltywidth);

  // mark the right side of the penalty box
  leftturn();
  delay(1000);
  pressselecttoconfirm();
  straightlinefunction(penaltylength);

  // move down to goal box
  leftturn();
  delay(1000);
  pressselecttoconfirm();
  float intermediate = (penaltywidth - goalwidth)/2;
  straightlinenopainting(intermediate);

  // paint top of goal box
  leftturn();
  delay(1000);
  pressselecttoconfirm();
  straightlinefunction(goallength);

  // paint side of goal box
  rightturn();
  delay(1000);
  pressselecttoconfirm();
  straightlinefunction(goalwidth);

  // paint bottom of goal box
  rightturn();
  delay(1000);
  pressselecttoconfirm();
  straightlinefunction(goallength);

  // go up to penalty mark line
  rightturn();
  delay(1000);
  pressselecttoconfirm();
  straightlinenopainting(goalwidth/2);

  // go out to penalty mark
  rightturn();
  delay(1000);
  pressselecttoconfirm();
  straightlinenopainting(penaltymark);

  lcd.clear();
  lcd.setCursor(0,0);
  lcd.print("Hold to paint");
  lcd.setCursor(0,1);
  lcd.print("penalty mark");
  delay(10000);

  lcd.clear();
  lcd.setCursor(0,0);
  lcd.print("Place stake on");
  lcd.setCursor(0,1);
  lcd.print("penalty mark");
  delay(5000);

  // go to lower left corner
  lcd.clear();
  lcd.setCursor(0, 0);
  lcd.print("Go to the lower");
  lcd.setCursor(0, 1);
  lcd.print("left corner.");
  delay(2000);
  pressselecttoconfirm();

  delay(1000);
  lcd.clear();
  lcd.setCursor(0, 0);
  lcd.print("Paint penalty");
  lcd.setCursor(0, 1);
  lcd.print("arc");
  delay(4000);
  lcd.clear();
  lcd.setCursor(0, 0);
  lcd.print("Penalty Arc:");
  lcd.setCursor(0, 1);
  lcd.print("Radius");
  lcd.setCursor(7,1);
  lcd.print(penaltyarc);
  delay(10000);
  pressselectwhendone();

  lcd.clear();
  lcd.print("Face along the ");
  lcd.setCursor(0, 1);
  lcd.print("lower field edge");
  lcd.setCursor(0, 0);
  delay(2000);
  pressselecttoconfirm();

  // go to centerline
  straightlinenopainting(length/2);

  //go to centerpoint
  straightlinefunction(width/2);
  delay(1000);
  lcd.clear();
  lcd.setCursor(0, 0);
  lcd.print("Place stake at");
  lcd.setCursor(0, 1);
  lcd.print("end of line.");
  delay(1000);
  pressselecttoconfirm();

  // finish centerline
  straightlinefunction(width/2);
  rightturn();
  delay(1000);
  straightlinenopainting(length/2);

  delay(1000);
  lcd.clear();
  lcd.setCursor(0, 0);
  lcd.print("Paint center");
  lcd.setCursor(0, 1);
  lcd.print("circle");
  delay(4000);
  lcd.clear();
  lcd.setCursor(0, 0);
  lcd.print("Center Circle:");
  lcd.setCursor(0, 1);
  lcd.print("Radius");
  lcd.setCursor(7,1);
  lcd.print(circleradius);
  delay(10000);
  pressselectwhendone();

  // paint rest of field- copied from above
  
  // paint penalty box
  // turn around to paint penalty area
  
  straightlinenopainting(topenalty);

  // paint right side of penalty box
  rightturn();
  delay(1000);
  pressselecttoconfirm();
  straightlinefunction(penaltylength);

  // mark the outside of the penalty box
  leftturn();
  delay(1000);
  pressselecttoconfirm();
  straightlinefunction(penaltywidth);

  // mark the right side of the penalty box
  leftturn();
  delay(1000);
  pressselecttoconfirm();
  straightlinefunction(penaltylength);

  // move down to goal box
  leftturn();
  delay(1000);
  pressselecttoconfirm();
  straightlinenopainting(intermediate);

  // paint top of goal box
  leftturn();
  delay(1000);
  pressselecttoconfirm();
  straightlinefunction(goallength);

  // paint side of goal box
  rightturn();
  delay(1000);
  pressselecttoconfirm();
  straightlinefunction(goalwidth);

  // paint bottom of goal box
  rightturn();
  delay(1000);
  pressselecttoconfirm();
  straightlinefunction(goallength);

  // go up to penalty mark line
  rightturn();
  delay(1000);
  pressselecttoconfirm();
  straightlinenopainting(goalwidth/2);

  // go out to penalty mark
  rightturn();
  delay(1000);
  pressselecttoconfirm();
  straightlinenopainting(penaltymark);

  lcd.clear();
  lcd.setCursor(0,0);
  lcd.print("Hold to paint");
  lcd.setCursor(0,1);
  lcd.print("penalty mark");
  delay(10000);

  lcd.clear();
  lcd.setCursor(0,0);
  lcd.print("Place stake on");
  lcd.setCursor(0,1);
  lcd.print("penalty mark");
  delay(5000);

  lcd.clear();
  lcd.setCursor(0, 0);
  lcd.print("Paint penalty");
  lcd.setCursor(0, 1);
  lcd.print("arc");
  delay(4000);
  lcd.clear();
  lcd.setCursor(0, 0);
  lcd.print("Penalty Arc:");
  lcd.setCursor(0, 1);
  lcd.print("Radius");
  lcd.setCursor(7,1);
  lcd.print(penaltyarc);
  delay(10000);
  pressselectwhendone();


  
  delay(1000);
  lcd.clear();
  lcd.setCursor(0, 0);
  lcd.print("Paint corner");
  lcd.setCursor(0, 1);
  lcd.print("circles");
  delay(4000);
  lcd.clear();
  lcd.setCursor(0, 0);
  lcd.print("Corner circles:");
  lcd.setCursor(0, 1);
  lcd.print("Radius 1yd");
  delay(10000);
  pressselectwhendone();
  
  
}

void U8fielddirections(int length, int width)
{
  // length = 50, width = 25
  // all measurements in yards
  float circleradius = 6;
  float halfline = 25;
  float goallength = 6;
  float goalwidth = 12;
  float cornerarc = 1;

  // Instruct the user to paint the outside rectangle.
  lcd.clear();
  lcd.setCursor(0, 0);
  lcd.print("Paint field");
  lcd.setCursor(0, 1);
  lcd.print("perimeter:");
  delay(2000);
  lcd.clear();

  // Go to bottom left corner.
  lcd.setCursor(0, 0);
  lcd.print("Go to bottom");
  lcd.setCursor(0, 1);
  lcd.print("left corner.");
  delay(2000);
  lcd.clear();

  // Replicated at bottom as pressselecttoconfirm();
  //Wait for select input.
  lcd.setCursor(0, 0);
  lcd.print("Press SELECT to");
  lcd.setCursor(0, 1);
  lcd.print("confirm location.");
  delay(2000);
  boolean waitingforselect = true;
  while (waitingforselect == true)
  {
    delay(50);
    if (read_LCD_buttons() == 4)
    {
      break;
    }

  }

  // mark the bottom line of the perimeter
  lcd.clear();
  lcd.print("Face along the ");
  lcd.setCursor(0, 1);
  lcd.print("lower field edge");
  lcd.setCursor(0, 0);
  delay(1000);
  straightlinefunction(length);
  delay(1000);


  // mark the right side of the perimeter
  leftturn();
  pressselecttoconfirm();
  delay(1000);
  straightlinefunction(width);

  // mark the top of the perimeter
  leftturn();
  delay(1000);
  pressselecttoconfirm();
  straightlinefunction(length);

  // mark the left side of the perimeter
  leftturn();
  delay(1000);
  pressselecttoconfirm();
  straightlinefunction(width);

  // turn around to paint goal area
  lcd.clear();
  lcd.setCursor(0, 0);
  lcd.print("Turn around.");
  pressselecttoconfirm();
  straightlinenopainting(6.5);

  // paint right side of goal box
  rightturn();
  delay(1000);
  pressselecttoconfirm();
  straightlinefunction(6);

  // mark the outside of the goal box
  leftturn();
  delay(1000);
  pressselecttoconfirm();
  straightlinefunction(12);

  // mark the right side of the goal box
  leftturn();
  delay(1000);
  pressselecttoconfirm();
  straightlinefunction(6);


  // go to upper left corner
  lcd.clear();
  lcd.setCursor(0, 0);
  lcd.print("Go to the upper");
  lcd.setCursor(0, 1);
  lcd.print("left corner.");
  delay(2000);
  rightturn();
  delay(1000);
  straightlinenopainting(6.5);
  pressselecttoconfirm();

  // follow top line
  rightturn();
  delay(1000);
  pressselecttoconfirm();
  straightlinenopainting(25);
  pressselecttoconfirm();


  // mark centerline
  rightturn();
  delay(1000);
  pressselecttoconfirm();
  straightlinefunction(12.5);

  lcd.clear();
  lcd.setCursor(0, 0);
  lcd.print("Place stake at");
  lcd.setCursor(0, 1);
  lcd.print("end of line.");
  delay(1000);
  pressselecttoconfirm();
  straightlinefunction(12.5);

  // get to other goal box
  leftturn();
  delay(1000);
  pressselecttoconfirm();
  straightlinenopainting(25);
  leftturn();
  pressselecttoconfirm();
  straightlinenopainting(6.5);

  // paint right side goal box
  leftturn();
  delay(1000);
  pressselecttoconfirm();
  straightlinefunction(6);

  // paint outside goal box
  rightturn();
  delay(1000);
  pressselecttoconfirm();
  straightlinefunction(12);

  // paint other side goal box
  rightturn();
  delay(1000);
  pressselecttoconfirm();
  straightlinefunction(6);

  // instruct for circle and corner
  delay(1000);
  lcd.clear();
  lcd.setCursor(0, 0);
  lcd.print("Paint center &");
  lcd.setCursor(0, 1);
  lcd.print("corner circles");
  delay(4000);
  lcd.clear();
  lcd.setCursor(0, 0);
  lcd.print("Center Circle:");
  lcd.setCursor(0, 1);
  lcd.print("Radius 6yd");
  delay(10000);
  pressselectwhendone();
  delay(1000);
  lcd.clear();
  lcd.setCursor(0, 0);
  lcd.print("Corner arcs:");
  lcd.setCursor(0, 1);
  lcd.print("Radius 1yd");
  delay(10000);
  pressselectwhendone();

}


// ////////////////////////////////////////////////////////////////////////////////////////
// HELPER FUNCTIONS
// ////////////////////////////////////////////////////////////////////////////////////////




void leftturn()
{
  lcd.clear();
  lcd.setCursor(0, 0);
  lcd.print("Turn 90 degrees");
  lcd.setCursor(0, 1);
  lcd.print("to the left.");
}

void rightturn()
{
  lcd.clear();
  lcd.setCursor(0, 0);
  lcd.print("Turn 90 degrees");
  lcd.setCursor(0, 1);
  lcd.print("to the right.");
}
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
